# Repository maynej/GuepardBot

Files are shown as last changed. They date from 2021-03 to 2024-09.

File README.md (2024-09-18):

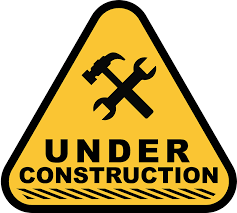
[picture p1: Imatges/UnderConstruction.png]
# GuepardBot 

STEMFIE adaptation to Baby MIT Cheetah 

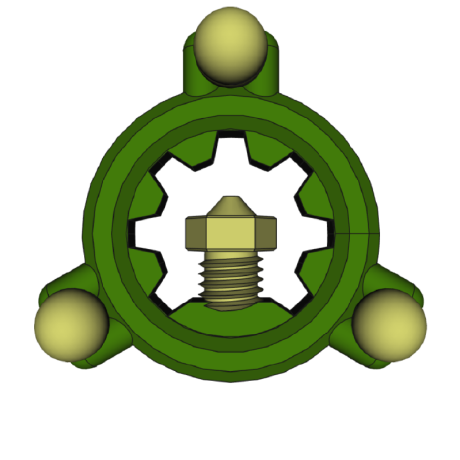
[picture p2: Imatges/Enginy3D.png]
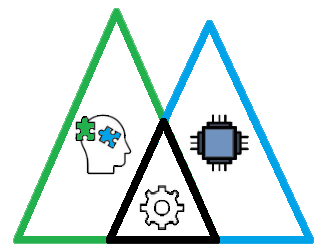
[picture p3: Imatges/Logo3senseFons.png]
Iniciat per [Artur Binefa](https://github.com/enginy3D) de enginy 3D  amb Freecad, i realitzat per [Jordi Mayné](https://github.com/maynej) des de Mechatronic Study 

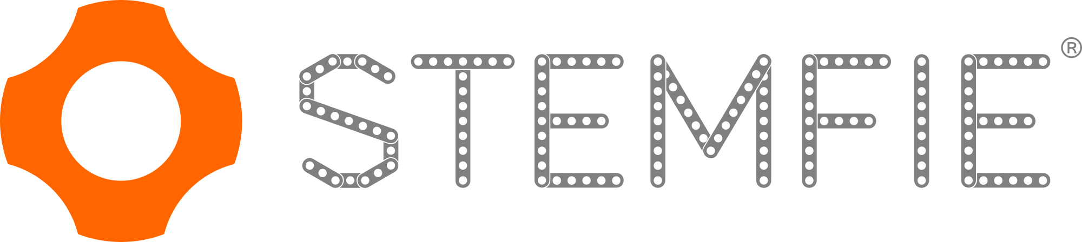
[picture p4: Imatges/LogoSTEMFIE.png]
STEMFIE es un projecte de construcció lliure, que s'imprimeix en 3D (http://stemfie.org) 

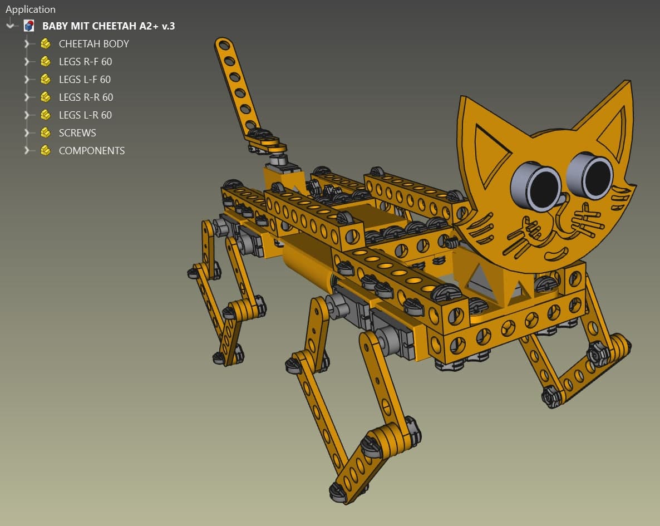
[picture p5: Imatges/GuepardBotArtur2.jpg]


Tota la [documentació es pot trobar en PDF](https://github.com/maynej/GuepardBot/tree/main/DOC).

STL per imprimir GuepardBot [aquí](https://github.com/maynej/GuepardBot/tree/main/STL).

## Suports 3D
  
Descripció         | Imatge          | Arxiu         
------------- | ------------- | ------------- 
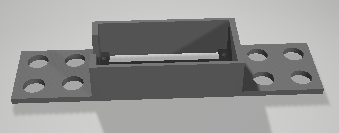
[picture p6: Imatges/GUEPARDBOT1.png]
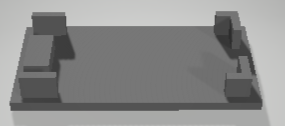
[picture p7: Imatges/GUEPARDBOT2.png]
Suport Arduino Nano i tapa |  | [Arduino Nano](STL/ArduinoNanoStemfie.stl), [Tapa Arduino Nano](STL/TapaArduinoNanoStemfie.stl)
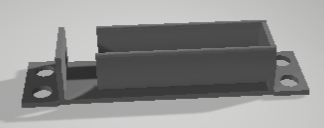
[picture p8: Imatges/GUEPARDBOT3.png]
Suport Bateria Li-ion 18650| | [18650](STL/18650.stl)
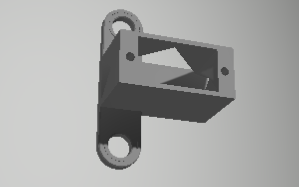
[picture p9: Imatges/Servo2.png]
Suport Servo-motor SG9|  | [ServoSuport 3H](STL/ServoSuport4migStemfie.stl), [ServoSuport 3V](STL/ServoSuport3VStemfie.stl)
Suport palanca Servo-motor SG9| |[Adapter SG9](STL/Servo9GAdapter_Stemfie.stl)
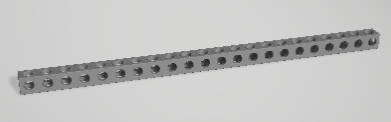
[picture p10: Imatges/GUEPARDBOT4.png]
Biga 22 | | [Biga 22](STL/Beam22.stl)
Biga 6 | | [Biga 6](STL/Beam1x1x6.stl)
Biga 4 | | [Biga 4](STL/Beam1x1x4.stl)
Tensor 4 | | [Tensor 4](STL/BraceSTR_ERR_BU04x01x00.25-SPN-BRC-0003.stl)
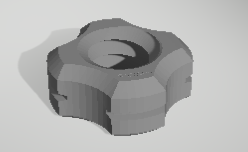
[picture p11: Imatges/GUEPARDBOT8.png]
Femella | | [Femella](STL/NutRH_BU01.00x5mm-SPN-NUT-0001.stl)
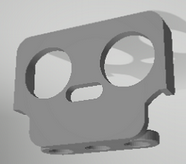
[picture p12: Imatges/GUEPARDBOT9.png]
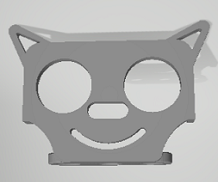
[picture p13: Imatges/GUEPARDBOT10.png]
Cara Guepard |  | [Cara Guepard](STL/SensorAsimetric3H_STEMFIE.stl)
Cargol BU00.50 | | [Cargol BU00.50](STL/ShoulderScrewRHD_RH_BU00.50-SPN-SSC-0042.stl)
Cargol BU00.75 | | [Cargol BU00.75](STL/ShoulderScrewRHD_RH_BU00.75-SPN-SSC-0043.stl)
Cargol BU01.25 | | [Cargol BU01.25](STL/ShoulderScrewRHD_RH_BU01.25-SPN-SSC-0045.stl)
Cargol BU02.00 | | [Cargol BU02.00](STL/ShoulderScrewRHD_RH_BU02.00-SPN-SSC-0048.stl)
Volandera | | [Volandera](STL/NutRHBU01.00x5mm-SPN-NUT-0001.stl)

## QR


## Llicència

Creative Commons Attribution-NoComercial-ShareAlike 4.0 International (CC BY-NC-SA 4.0)

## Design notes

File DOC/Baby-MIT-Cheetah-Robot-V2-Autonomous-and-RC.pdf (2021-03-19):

instructables

Baby MIT Cheetah Robot V2 Autonomous and RC (http://www.instructables.com/id/Baby-MIT-Cheetah-Robot-V2-Autonomous-and-RC/)

by jegatheesan.soundarapandian (http://www.instructables.com/member/jegatheesan.soundarapandian/)

Very Very Sorry Now only found the legs design in the tinkercad has problem, thanks to Mr.kjellgnilsson.kn (https://www.instructables.com/member/kjellgnilsson.kn/) for check and inform me. Now change the design le and upload. Kindly check and download. Those who already download and printed I am very very sorry, i never notice and dont know how it change.

Actually that previous design also works but the joint is very thin and it break while fast steps.

Baby MIT Cheetah Robot (https://www.instructables.com/id/Baby-MIT-Cheetah-Robot/) is the previous version of this robot. I did lot of changes in this version. But even more want to done. But this version very very simple for any one to design. In the previous Version Body is made of wood but in this version i 3D print the body so if any one want to this this robot its very very easy to do. Just download and print the body and leg, then screw the servos.

I plan for the top cover after complete the project, but current due to state wise lock i cant able to get the cover from supplier. Even though it looks cute on carrying two batteries like Robot cow bulk in the

stomach.

This is not upgraded from old its completely new build. So all the steps are included in this instructables, you dont want to refer the version1 instructables.

M ajor changes Done

1) Body is 3D printed.
2) Its Bluetooth control as well as Autonomous.
3) Battery Operated (The strong battery 18650 2Nos allow to run for long hours, From start design to complete i test it for more than 2 hours but still work in battery).
4) Lot of changes in the arduino program, we able to change the moving speed. If we have foot for the robot, it never fall and at that time change the variable smoothdelay in the program and even we see the slow motion walk.

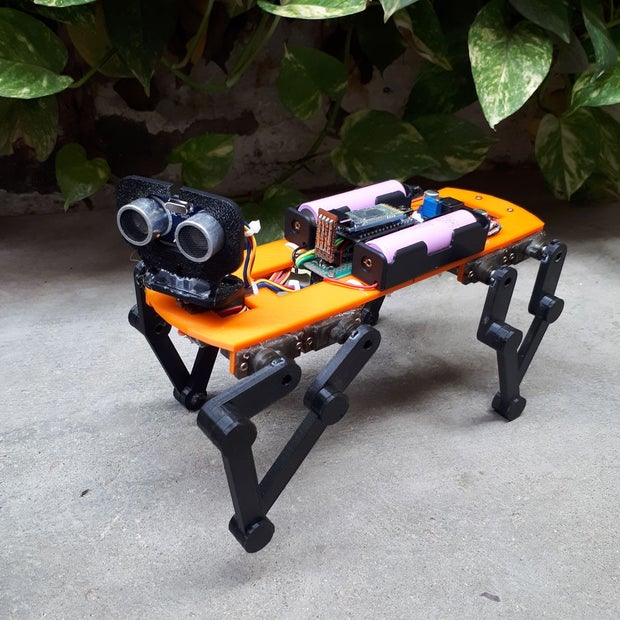
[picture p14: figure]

Baby MIT Cheetah Robot V2 Autonomous and RC: Page 1

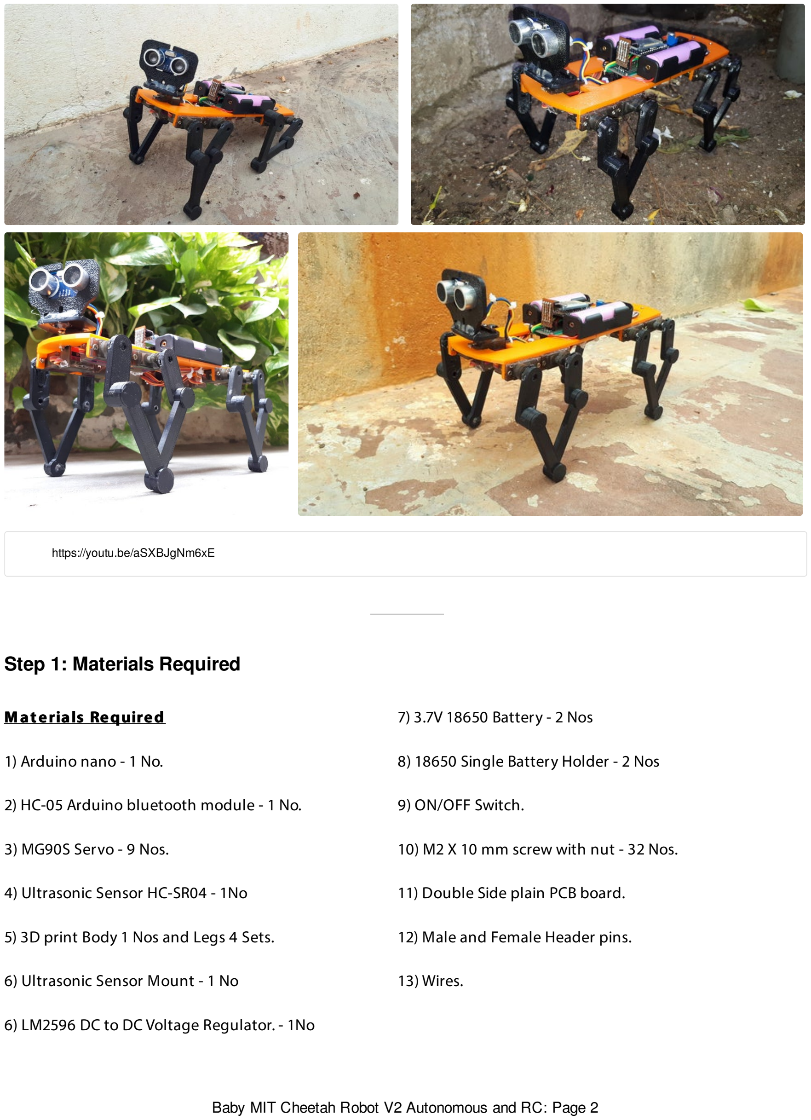
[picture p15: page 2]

### Step 1: Materials Required

https://youtu.be/aSXBJgNm6xE

M at erials Required

1) Arduino nano - 1 No.
2) HC-05 Arduino bluetooth module - 1 No.
3) MG90S Servo - 9 Nos.
4) Ultrasonic Sensor HC-SR04 - 1No
5) 3D print Body 1 Nos and Legs 4 Sets.
6) Ultrasonic Sensor Mount - 1 No
6) LM2596 DC to DC Voltage Regulator. - 1No
7) 3.7V 18650 Battery - 2 Nos
8) 18650 Single Battery Holder - 2 Nos
9) ON/OFF Switch.
10) M2 X 10 mm screw with nut - 32 Nos.
11) Double Side plain PCB board.
12) Male and Female Header pins.
13) Wires.

### Step 2: 3D Print Leg

### Step 3: 3D Print Body

### Step 4: Circuit Plan and Develop

Use Tinkercad (http://tinkercad.com/) to design the Legs and Body. And 3D print it in A3DXYZ. (https://a3dxyz.com/) https://www.tinkercad.com/embed/jtZIKGD5QBL?editbtn=1

Download the Tinkercad Files and Print it. Some holes are put in the body while xing and wiring.

https://www.tinkercad.com/embed/a8EDaNkRZpk?editbtn=1

As per plan we want to drive 9 servos. So i user Digital pins 2 to 10. Connect the pin to the servo pins using male connector. Arduino TX RX is connected to bluetooth RX and TX, Ultrasonic sensor Echo and Trigger connected to Pins A2 and A3 and power supply for bluetooth and Ultrasonic sensor is given from arduino 5V. For Arduino Vin is given directly from 2 3.7V battery 18650. For servos Supply given from same 18650 but through LM2596 voltage regulator.

I use double side PCB to make shield. While use double side PCB be careful while creating track in the

PCB, Molten lead pass through the holes and ll in the next side. Use Female header pins in the double side PCB to connect the arduino nano and in the opposite side of the board use male header pins to connect the servos, I soldered 12 male connectors from 2 to 13. Solder female header pins to connect the HC-05 bluetooth module on the board. And Male header pins for Ultrasonic sensor. Four male header pins from GND, Vin of the arduino, dummy and last one for servos vin. The Circuit is very small.

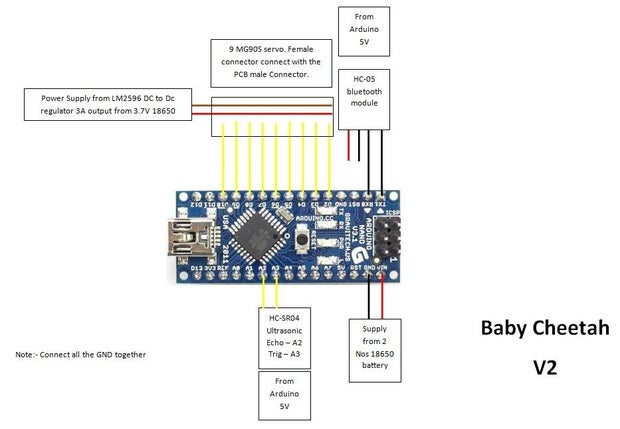
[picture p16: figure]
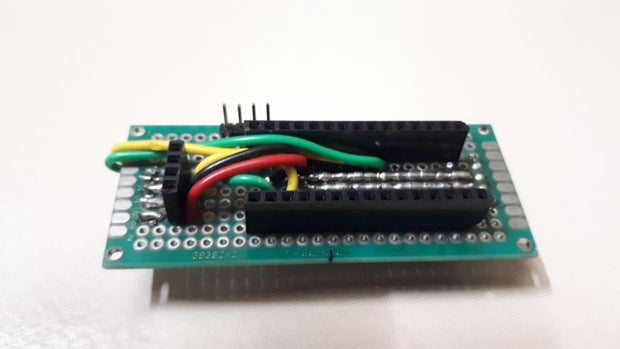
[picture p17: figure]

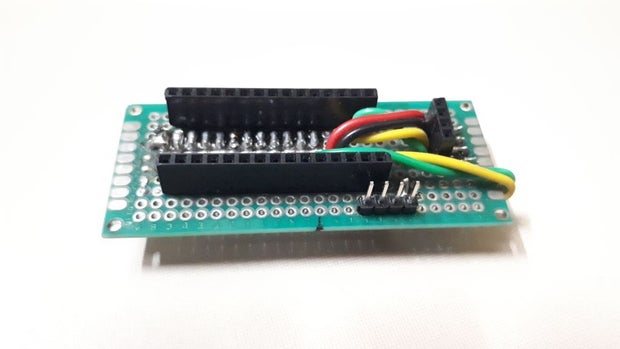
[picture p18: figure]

### Step 5: Assemble Leg

There are 7 pieces in the a single set leg. Like wise 4 sets available. Join the leg links where two pieces connected with servo has a servo horn slot on the back side and its is 30mm length hole to hole. and the link pieces are 6 cm from hole to hole.In the 3D model i set only 0.1mm diHerence gap for links, so it hold very tight. I use ne emery sheet to increase the hole size and x the links.First join the left side and then the right side and then the bottom.Now use the top screw like cap to hold the links. Join all the four sets.

The screw like plastic piece extend up to the back side of the links. Use feviquick (quick xing liquid) to paste the holder permanently with the legs. Be careful while pasting, Don't allow the feviquick to Low inside the moving joins. Then fully paste the servo horn on both side of the leg. Now check and found the movement is correct. The links are 5mm thick so its hard.

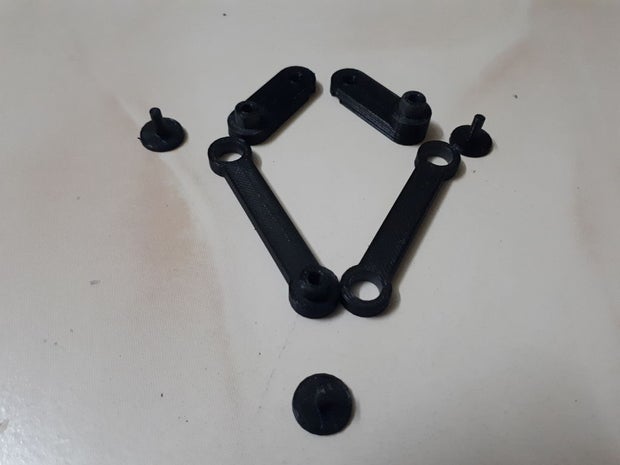
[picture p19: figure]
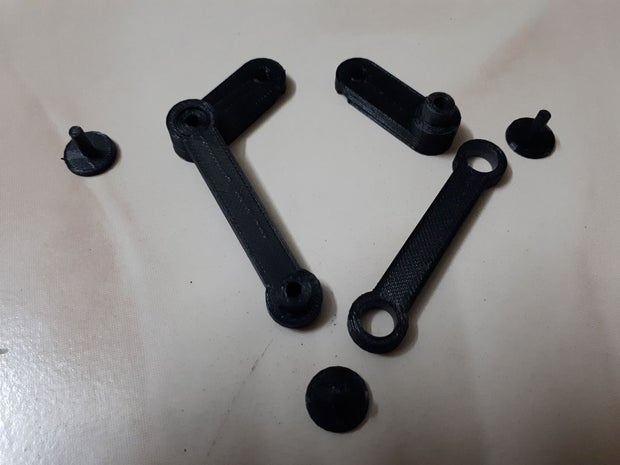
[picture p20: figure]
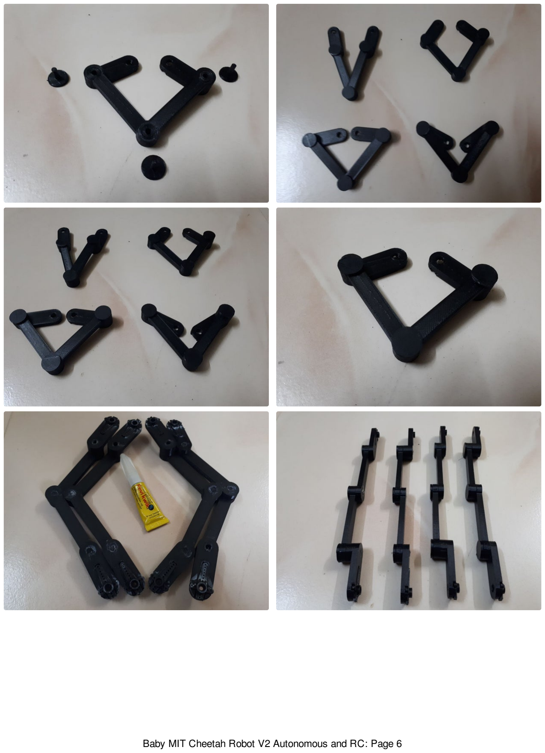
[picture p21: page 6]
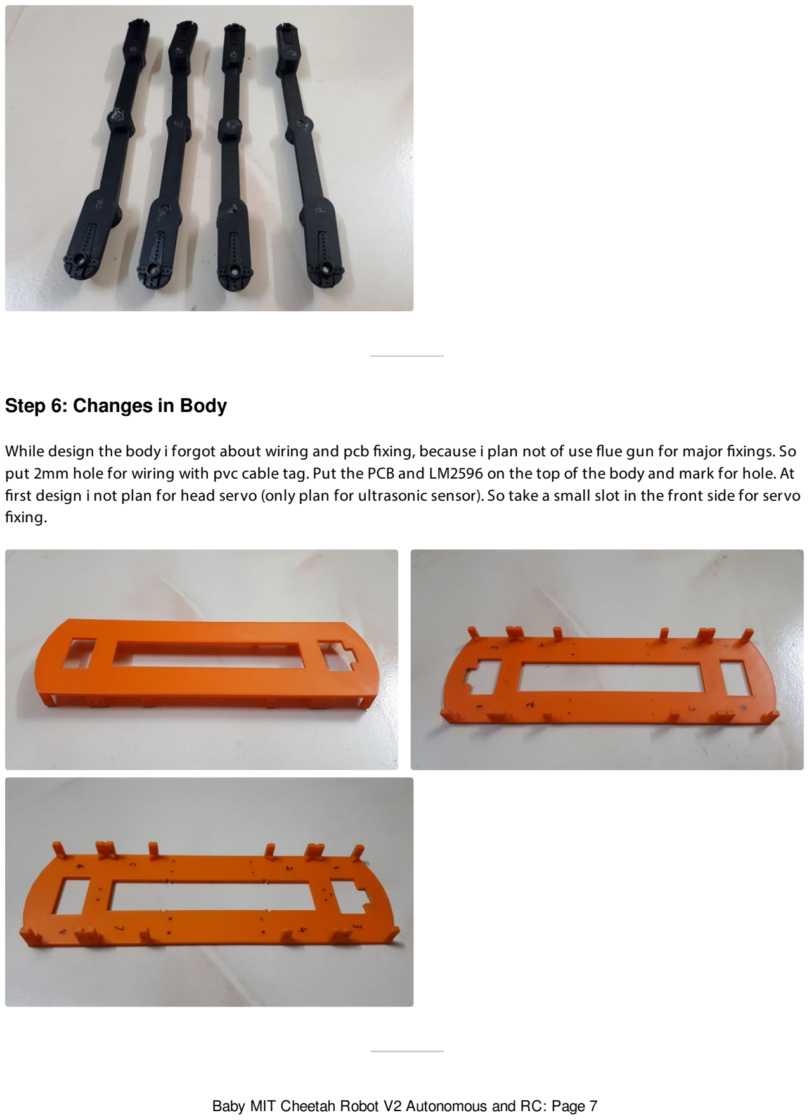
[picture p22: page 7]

### Step 6: Changes in Body

While design the body i forgot about wiring and pcb xing, because i plan not of use Lue gun for major xings. So put 2mm hole for wiring with pvc cable tag. Put the PCB and LM2596 on the top of the body and mark for hole. At rst design i not plan for head servo (only plan for ultrasonic sensor). So take a small slot in the front side for servo xing.

### Step 7: Screw Servos With Plan

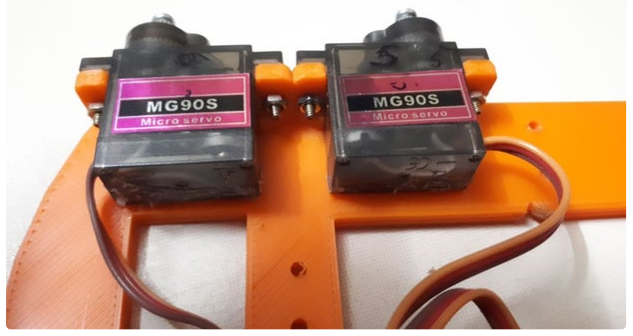
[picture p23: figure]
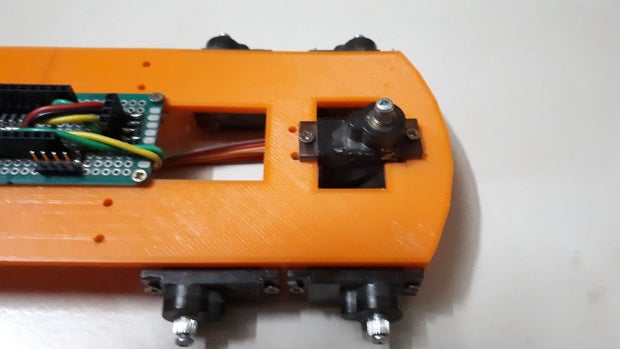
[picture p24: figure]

### Step 8: Screw Circuits

First step is to x the servos. This project has 9 servos. Servos pin connection pin no, name in arduino program and location marked in the rst image. I use M2 X 10mm screw and nut (At rst plan for nickel screw but while see the force of the leg while walking i feel if screw and nut is use then its very tight and not damage while walking). Screw all the servos as like the photo and as per the pin number hot glue the servo connectors one after the another. So its very easy to plugin and also no chance to change the pins.

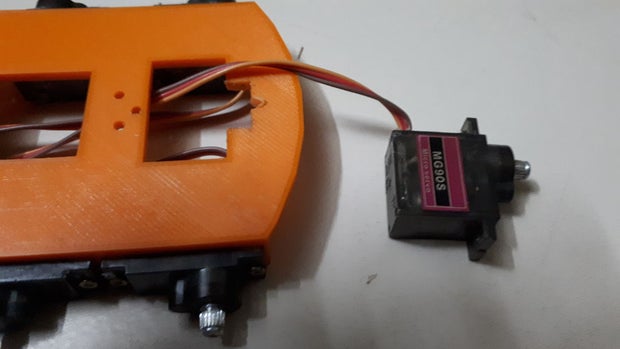
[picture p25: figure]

Put the shield over the body and screw it in the edges with the body on all four sides in the slot. Mark a center line in the body and keep the circuit center with the body center. Screw the DC to DC regulator board LM2596 on the back side of the body.

### Step 9: Power Supply Wiring and Checking

ON/OFF Power switch which i got is the screw option on the front. So i cut a small plain pcb and tie the switch in that pcb and hot glue it. Now put 2mm hole on both side in the pcb. Mark that holee in the back of the body and drill it. Screw the switch with 2mm bolt and Nut. Soldering the battery positive wire through this switch to the LM2596 dc to dc regulator input.

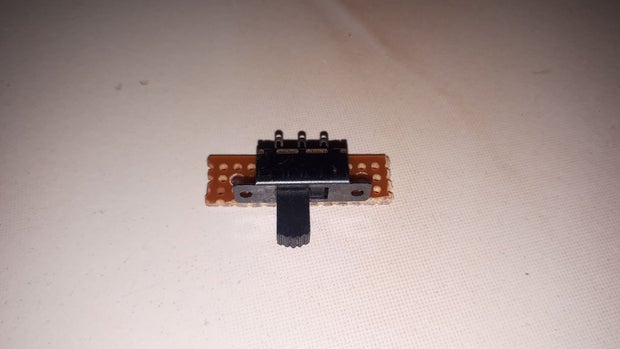
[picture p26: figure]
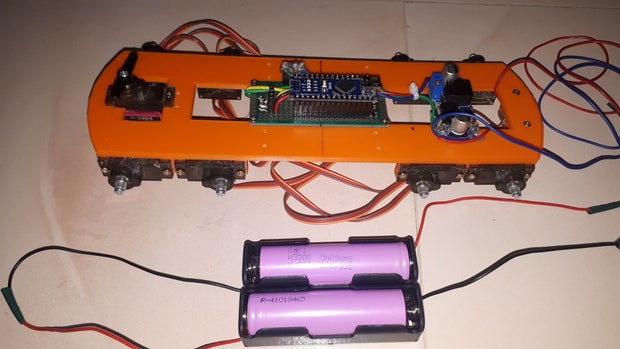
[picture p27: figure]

### Step 10: Under Devepment Work Place

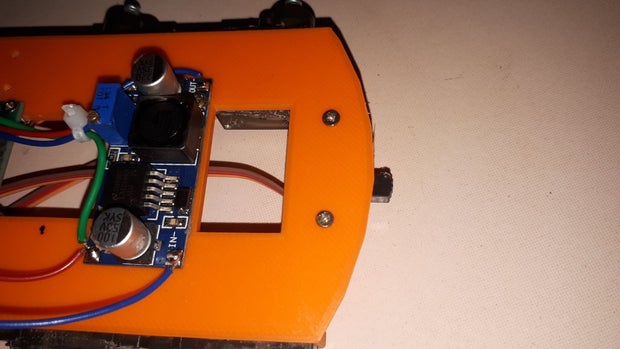
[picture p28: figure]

### Step 11: Head Fixing (Ultrasonic Sensor Fixing)

My Work place (also my bed room) at the time of developing baby cheetah robot. See the baby cheetah in the center its growing. Can you trace the tools around me. Organize it after work at night 3 is the diMcult task.

Ultrasonic holder is available online. But the horn screw holder is for the SG90 servo screw. So i increase the hole size of the holder and screw the servo horn with the ultrasonic sensor holder. Make a 4 wire female to female header pin wire extension. Already solder male header in the shield with wiring for ultrasonic. Put the head servo to

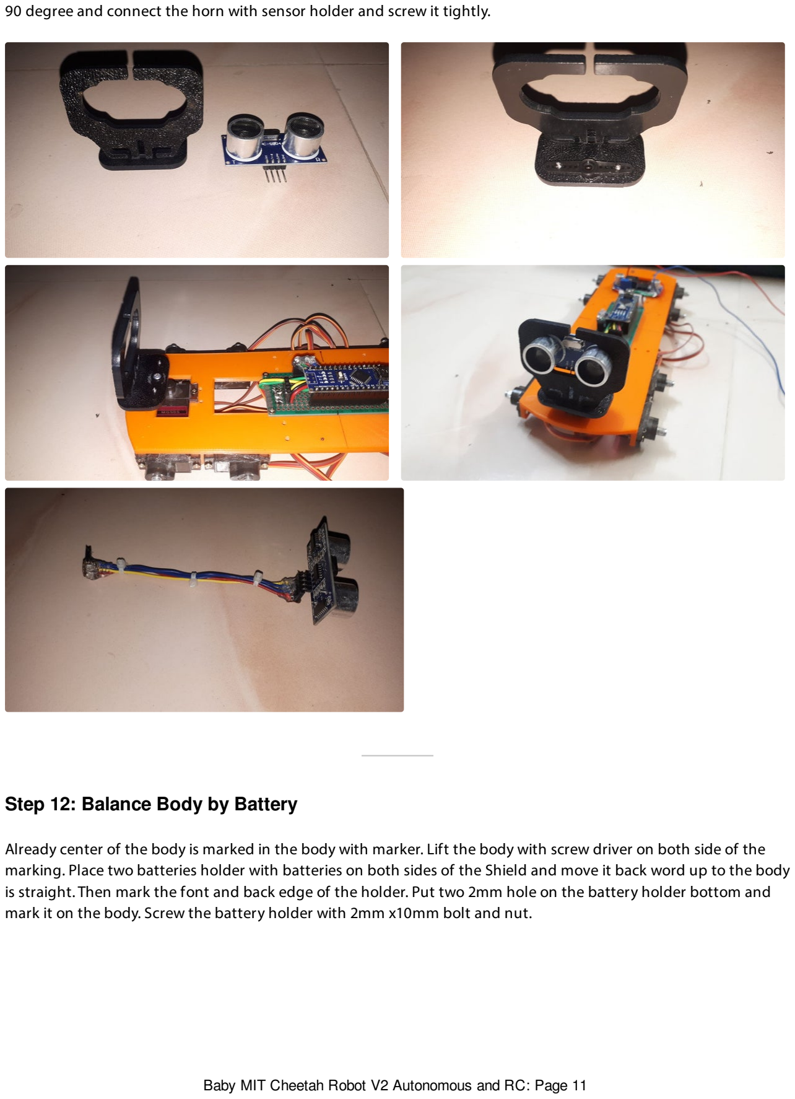
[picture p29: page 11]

### Step 12: Balance Body by Battery

90 degree and connect the horn with sensor holder and screw it tightly.

Already center of the body is marked in the body with marker. Lift the body with screw driver on both side of the marking. Place two batteries holder with batteries on both sides of the Shield and move it back word up to the body is straight. Then mark the font and back edge of the holder. Put two 2mm hole on the battery holder bottom and mark it on the body. Screw the battery holder with 2mm x10mm bolt and nut.

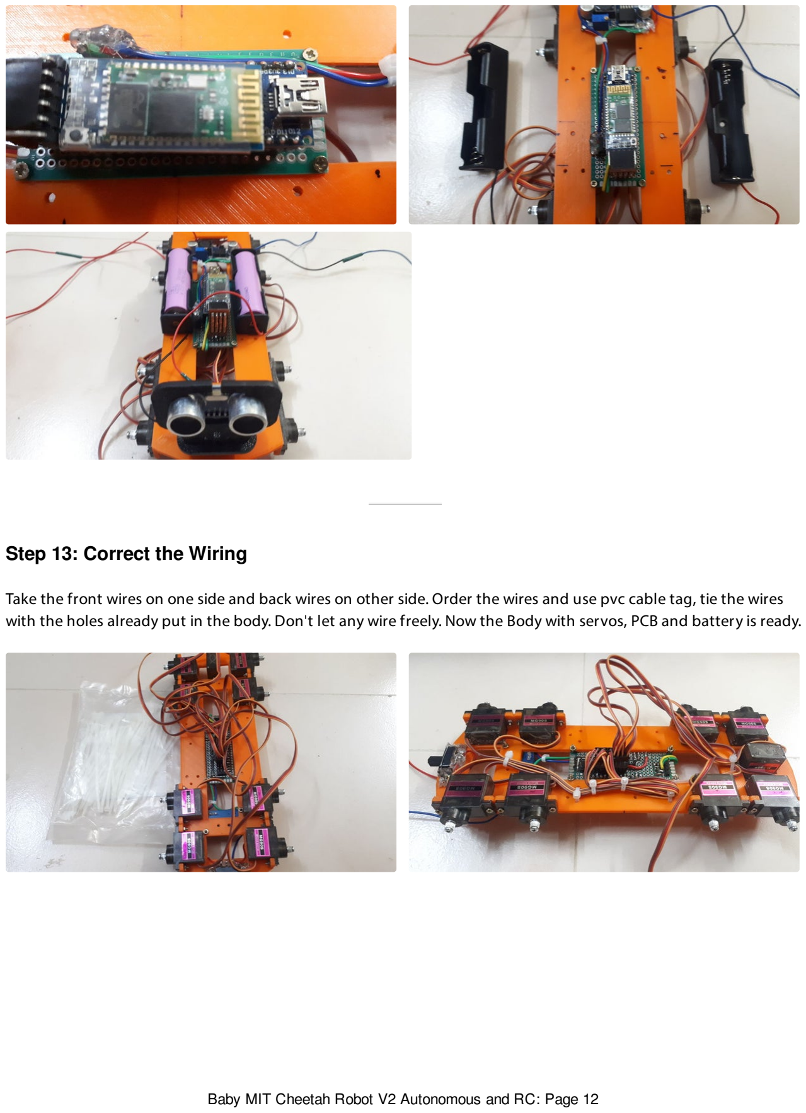
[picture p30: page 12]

### Step 13: Correct the Wiring

Take the front wires on one side and back wires on other side. Order the wires and use pvc cable tag, tie the wires with the holes already put in the body. Don't let any wire freely. Now the Body with servos, PCB and battery is ready.

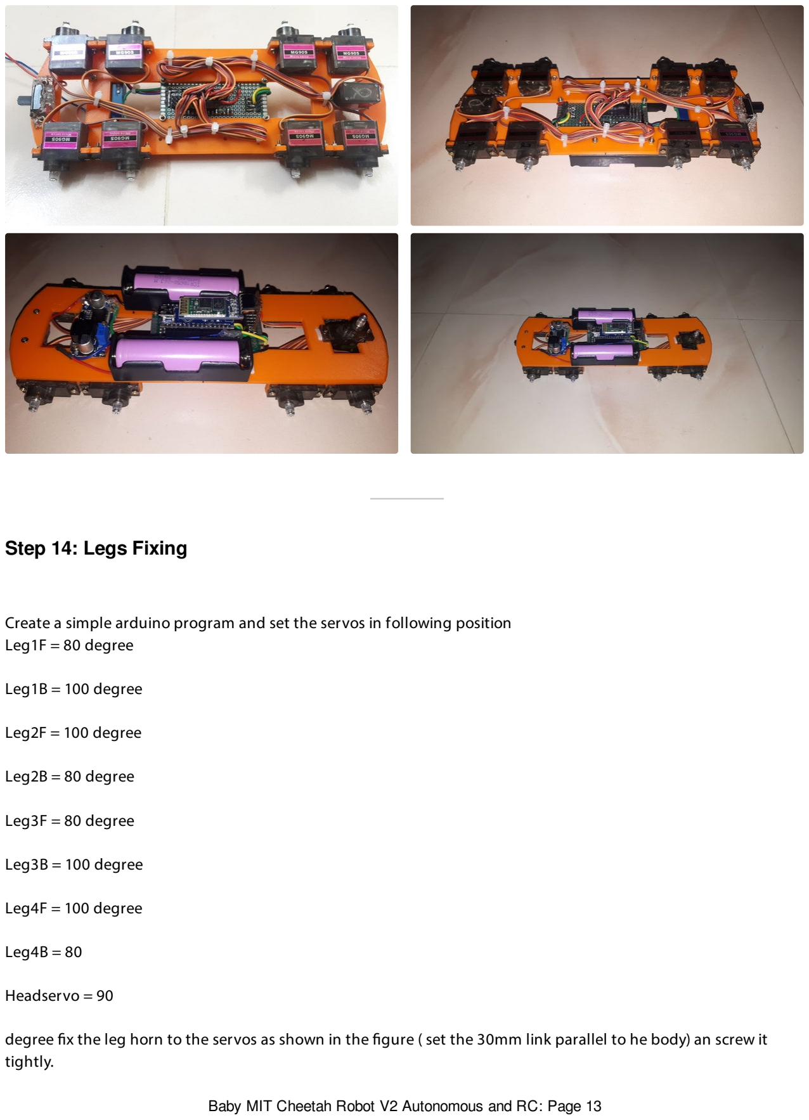
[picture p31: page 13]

### Step 14: Legs Fixing

Create a simple arduino program and set the servos in following position Leg1F = 80 degree

Leg1B = 100 degree

Leg2F = 100 degree

Leg2B = 80 degree

Leg3F = 80 degree

Leg3B = 100 degree

Leg4F = 100 degree

Leg4B = 80

Headservo = 90

degree x the leg horn to the servos as shown in the gure ( set the 30mm link parallel to he body) an screw it tightly.

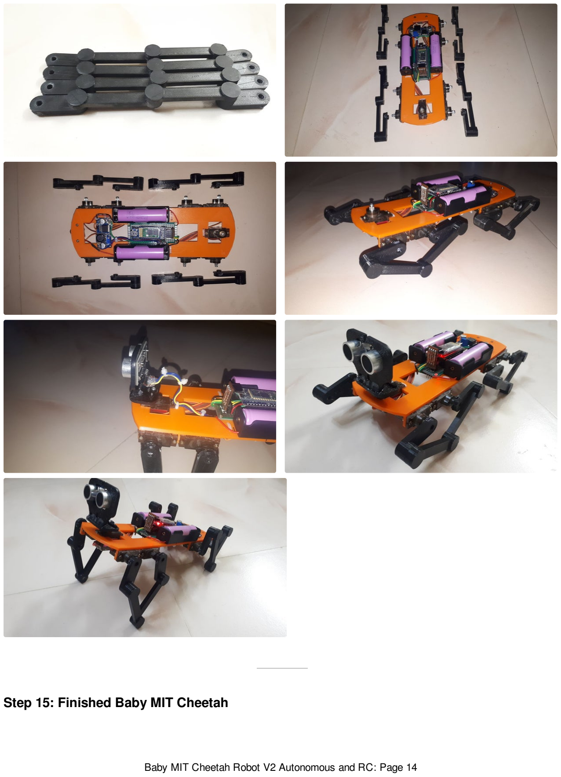
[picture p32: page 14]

### Step 15: Finished Baby MIT Cheetah

### Step 16: Android Code

Download the apk le from here (https://drive.google.com/file/d/1ljjOWiZYqTx6P_n0Vq42K3Er0TnjODdW/view?usp=sharing)

Download the aia le from here (https://drive.google.com/file/d/1TBjouGvm-IVyqHDKxgXw9jgRAbJs5Jhc/view?usp=sharing)

Its a very simple program developed in Android with MIT App Inventor (https://appinventor.mit.edu/) . All the buttons send a character as per press and release image. So far 21 characters used for each action. When arduino received this character through bluetooth it works as per the character received.

Download the app from google drive by click the above link and install it in the mobile.

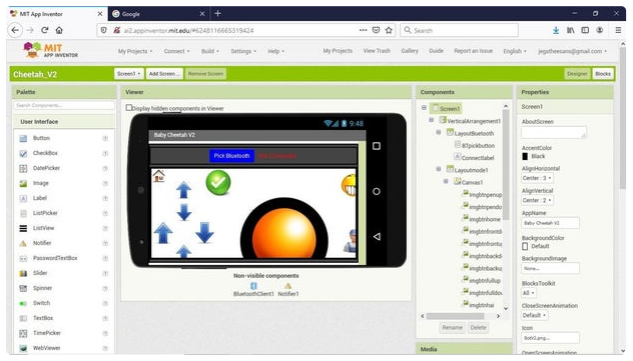
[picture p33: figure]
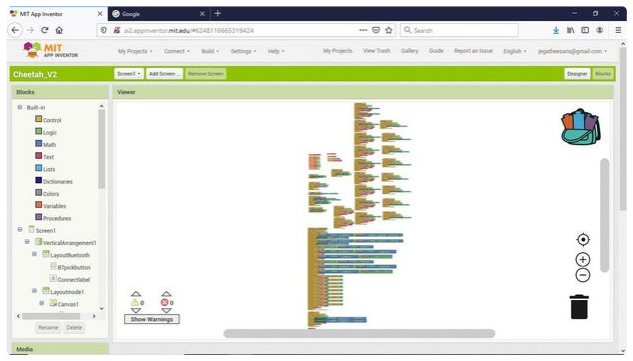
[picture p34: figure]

### Step 17: Keys From Android

List of characters send by the Arduino is given below

G Front left
F Front
I Front Right
L Left
S Stop
R Right
H BAck left
B BAck
J BAck right

U Up
D Down

W Front only down
X Back only down
Y Front only UP
Z Back only UP

O Fullstand
P Fullshit

C Check
V Hai

M Manual
A Auto

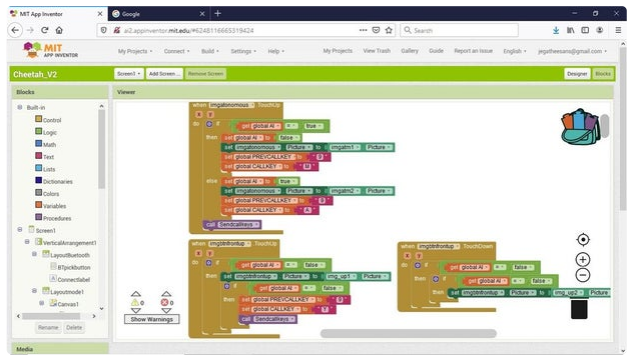
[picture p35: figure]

### Step 18: Run Android App

In the mobile Switch on the Bluetooth and Open Baby Cheetah V2. Click the pick bluetooth and select the arduino bluetooth HC-05. The control screen opens. New addition in the control screen compare to version one is. Auto and manual, if switch to auto then all other buttons are not able to use. Switch to manual mode to activate control.

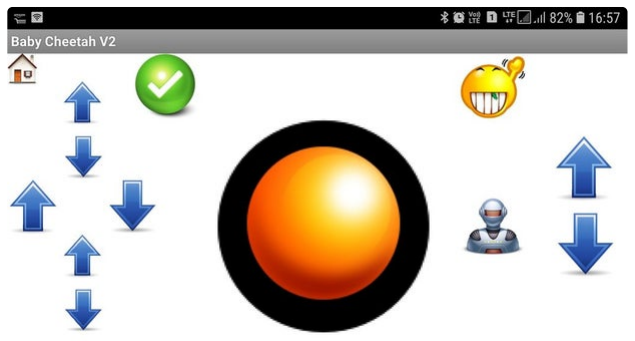
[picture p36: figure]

### Step 19: Arduino Code

### Step 20: Arduino Major Changes

Download the arduino code from Google Drive (https://drive.google.com/file/d/1eyzs1xH_40GEmCUdIiTCoEEMSyVstiyJ/view?usp=sharing)

The main aim of the arduino program is to keep the body in the same position even walk and turn. For

that angle of the leg movement is calculated in each height and put it in a multidimensional array. As per the commands received from the android the program check the array and move the leg in that direction. So the body is in the same height while walk and turn.
Cheetah walk funny like front leg in full height and back leg full down. Like wise wise verse. Like wise it also run in all heights.

M oving speed

In the previous version no servo control is provided so the servo move at its full speed. But in this version a seperate procedure us written for servos speed control. So whole program is changed by intialize the servo position want to move to the procedure. All the 8 leg servo motor last postion is recorded and with the new position nd the max diHerence of all the 8 motors. With that max diHerence divide all the steps want to move individually and with a for loop repeated for max steps with delay, we change the leg speed here.

Autonomous

When you switch the auto mode in the android. Auto run set to true in arduino. In the Autonomous mode the robot move automatically with the help of ultrasonic sensor.

How It works

1) First the robot go to full stand position.
2) Move forward and check the distance of obstacles from the robot.
3) If the distance is more than 5cm then its walk front else it stop.
4) First it reduce the height to up to 4 steps one by one.
5) If the obstacle is just a gate it never found obstacle at reduced height, then it move forward by crealing. After some xed movement it stand up and repeat the action.
6) Even down to 1 height and found the obstacle, it again stand at lle height (5th position)
7) Turn the head degree from 90 to 0 and note the distance and turn head to 180 degree and note the distance. Then head go to 90 degree.
8) Refer the left side distance and right side distance,

turn to the direction with long distance.

9) After turn move to front and goto step 2.

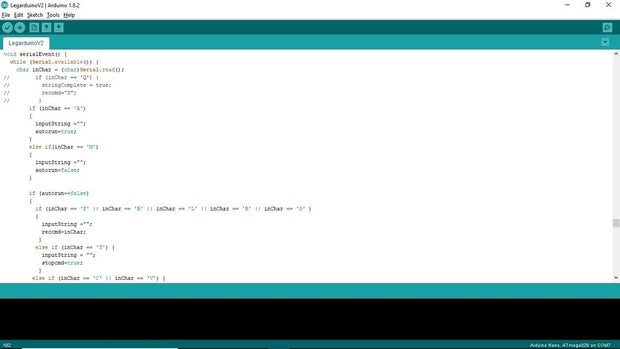
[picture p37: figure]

### Step 21: Autonomous Video

### Step 22: Baby Cheetah in RC Action

Open the App and connect the robot and click to auto mode (man in the app change to robot). Now see the movement, move forward and see a obstacle and reduce its height step by step, even it has obstacle. So it stand up and see left and right, in the left side i put a corrugated board. So right side has long way and it turn right and walk.

https://youtu.be/TQZb3RycQOs

Even through Autonomous mode is very nice. Kids like to play with control. Here are some videos with fun action of the robot. It say hai by show leg and shack heads. Orange black combination is like by all. I plan for the top cover only after x the head and design, but due to lock down i cant able to get the top cover. When cover work completed i put a photo shoot and

upload here.

Thank you for going through my project.

Lot more to enjoy | Don't forgot to
comment and encourage me friends .

Thank you for this great project. Would it be possible to have the .aia file for MIT app inventor please ? Best regards.

Now, I uploaded in google and give the link in step 16 please download it.
thank you so much.
Any chance you have Apple iOS code for this project? I'm making this with my son and we don't have an android device. Are there any other ways of controlling this robot? Our first RC project. The Amazon bill for the parts comes to over $100 CAD, so want to make sure it's money well spent to introduce my son to robotics. I really like the looks and description of this project.
Sorry sir i have no apple phone and i dont know how to code in ios. But MIT app inventor has new options to code in ios, may you try it..... Its very easy to program in MIT app inventor even i have no basic knowledge in android but i able to create app in android.
Sounds like something worth learning. You make it sound easy enough for my kids to learn and use too. :)
I have been
looking at your code, and would like to make several constructive
criticisms. 1. There are virtually no
comments in the code, which makes it difficult to follow. 2. There are many
lines which have been commented-out. Are this needed or can they be deleted? 3. There is a section (lines 142 – 150) that appear to be the initial servo setup positions, prior to attaching them. Is this correct? 4. There is no indication
which leg is which. Is leg 1 the Front Right and Leg 2 the Rear Right? 5. You have not included your name in the code. With such a great project, you should give yourself credit and include your name as the author. Please take these as constructive.

I have
designed and printed a TPU ‘foot’ and will let you know how it works.

Regards. Tony

1) Sorry i develop step by step so i don't comment.
2) Comment lines are not require u better delete it.
3) Yeah it is the initial servo setup but even it comment same is done in Servomovement(), so no need to uncomment for set up use the same program once setup run its is in the inital stage.
4) see step 7 ist image the image detailed the servo position.
5) Thank you for your complements. For more details feel free to mail me.
Hi, Really Nice project !!!
I`m thInking about build one myself. But instead of using those 18650 Batterys, I would use one of those cheap chinese Powerbanks(No need for the LM2596 voltage regulator). With an ESP32 dev kit that already has onboard Bluetooth. Would make it lot easyer.

Thank you very sir....
ESP32 is a nice idea. But using power bank is not good idea because at first i try in some other project and found while servo working it draw more current and sudden variation in voltage, this make the arduino 5v supply to reduce power and Arduino restart at when ever servo start, because the power bank out put is only 5v its is the minimum voltage for arduino. Also most of the power banks has 18650 batteries inside with same dc to dc power regulator. If you have power bank try it and send the result.
Very Very Sorry Now only found the legs design in the tinkercad has problem, thanks to Mr.kjellgnilsson.kn (https://www.instructables.com/member/kjellgnilsson.kn/) for check and inform me. Now change the design file and upload. Kindly check and download. Those who already download and printed I am very very sorry, i never notice and dont know how it change.

Actually that design also works but the joint is very thin and it break while fast steps.
Links Final Print on TinkerCAD shows edited 2019. Is this the latest or am I looking in the wrong place? Thanks!
Yeah it is the last one i start make this project in 2019 with my first version.
Caught my attention... I'm a small robot fanatic and this one really simple and cute to have! Thank you very much
Very nice project. Your Bill of Materials says 8 sets of legs but don't we only need 4?
Thank you very much.......Sorry i wrongly entered, now i changed the sets thank you very much... It's really good but:
It needs rubber feet so it can get a foothold. It's like walking on ice as it is,
Tjhank you very much.....yeah rubber in feet is better but for turning we want slippery floor. Please check my previous version the leg movement is calculated as per walk so with out rubber also not affect walk. But want to extend the leg that reduce the tilt while two leg in air.
Counl an Arduino UNO be used instead of a nano?
Yeah sure...
you don;t seem sure - is it because the nano is smaller/newer or you don't agree with the UNO for some functional reason?
For this project U can use UNO also, because i dont use any advance library i use only digital pins to control servo. But for this frame uno is over size. U want to put the board over the battery...
The sequel we probably didn't deserve, but we needed all the same!

Thanks for giving this little bot a remake - an idea this good definitely deserved it.
Thank you very much...
Very nice and innovative project. I like the leg action. I suggest adding another servo for a tail. Also, an audio output so your cat could purr or growl, or a dog version could bark.
Thank you very much...I plan to add another 4 more servos for walk side wise like MIT Cheetah.... Awesome project and very well written instructable! Even the previous version deserved being featured. Congratulations, man
Thank You very much...
This will be my next project, good work. I will try to add a TPU foot to the base of the leg. Also, I will use an HM10 Bluetooth module to connect to my iOS device. Do you know if there is a similar app builder for iOS? Thanks

Try it its very interesting. I have no idea about ios. But MIT App inventor now launch new page for ios developer.

Thank you very much....Try it its very easy.....I have some other plan to make it more easy if you able do it. In the leg make the joints easy remove then no need to stick.

Awesome build,! Will be printing this shortly lol
It is a gteat little concept and will follow your progress on it. An idea is to add a 16ch servo controller that would free up a lot of pins for other sensors/audio etc. :)
Thank you very much.....Yeah in previous version also some persons suggest it....due to i want to bring all in one shield i never try that. If more sensors in the future i force to use it.
That's doggo not cheetah. Cute build though! Keep it up.

Thank You very much
so good, keep it up buddy
Thank You very much.....
did you have ultrasonic sensor in the V1? the one with the blue cover on the body. I am doing a project but I cant seem to find any plastic that the ultrasonic sensor can see thru, any ideas? thanks in advance.
V1 is a basic version it has no ultrasonic sensor and no batteries. Even lot of arduino code is updated in V2.
Awesome. I would like to try. kindly can you send me the dimensions for the body and legs. Thank you very much....step2 and step3 you can able to download the tinker card file. If you want to print use it or open it in tinkercard and you able to find the dimension. It you want to do it manually please refer my previous version https://www.instructables.com/id/Baby-MIT-Cheetah-Robot/. (https://www.instructables.com/id/Baby-MIT-Cheetah-Robot/)
Buen proyecto trataré de recrearlo saludos desde la mitad del mundo Ecuador.
Muchas gracias señor ...

Thank you very much sir.... Its very easy to make it give a try....One small suggestion while design for leg foot join increase the height of the cylinder by 1 inch in the cap and in the base piece. So the robot not tilt even walk in very slow motion. For walk in slow motion increase the smooth delay in the program.
awesome project
Thank You very much sir........
nice clean build and well written instructable! thanks for sharing! Thank You very much sir....

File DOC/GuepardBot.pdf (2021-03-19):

JORDI MAYNE V0 – 2021 | 1

## GuepardBot

GuepardBot es una rèplica del Baby Cheetah https://www.instructables.com/Baby‐MIT‐Cheetah‐Robot‐V2‐Autonomous‐and‐RC/ feta amb estructura Stemfie.

El Skecth de funcionament és el mateix de Baby Cheetah, també l’aplicació per el smartphone/tablet.

Material Electrónic

1x Arduino Nano

2x Bateries 18650 3.7V amb terminals

9x servos SG9

1x Sensor de ultrasons HC‐SC04

1x Bluetooth HC‐05

1x Placa regulador LM2596

1x Interruptor

Material 3D

2x Beam 22

2x Beam 4

1x Beam 6

8x Servo Suport 3V Stemfie

1x Servo Suport 4mig Stemfie

34x Nut BU01.00x5 ‐SPN‐NOT‐BU0001

30x BU01.25 ‐ SPN‐SSC‐0045

2x BU02.00 ‐ SPN‐SSC‐0048


2x 18650


1x CPU Arduino Nano


1x Tapa Arduino Nano

1x Suport SensorAsimetric 3H

1x Servo9G Adapter

1x Brace BU04x01x00.25 ‐ SPN‐BRC‐0003

1x Screw BU00.75 ‐ SPN‐SSC‐0043

1x Screw BU00.50 ‐ SPN‐SSC‐0042

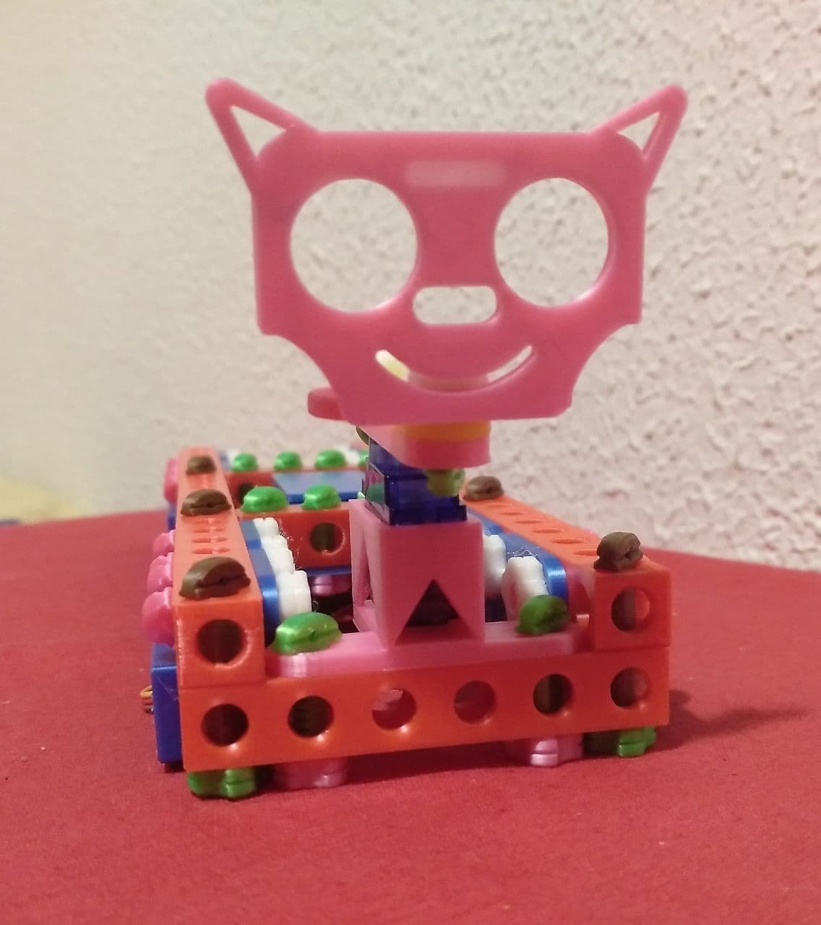
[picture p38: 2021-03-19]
Imatges/Guepard1.jpg

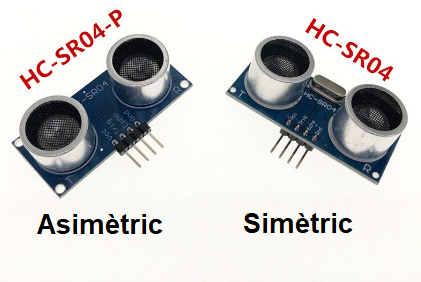
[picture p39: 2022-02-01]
Imatges/HC-SR04P vs.png

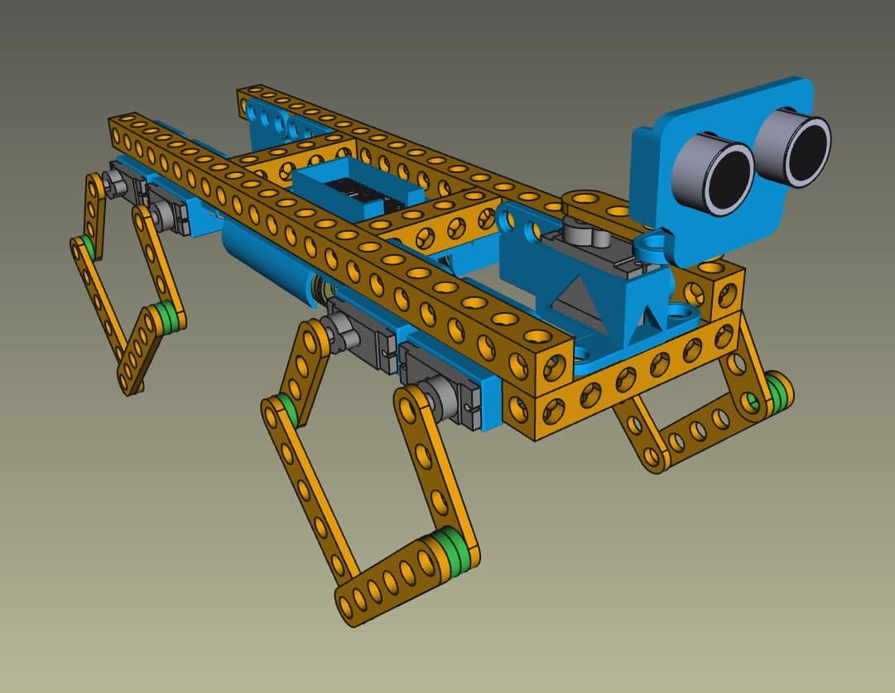
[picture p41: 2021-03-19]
Imatges/GuepardBotArtur1.jpg

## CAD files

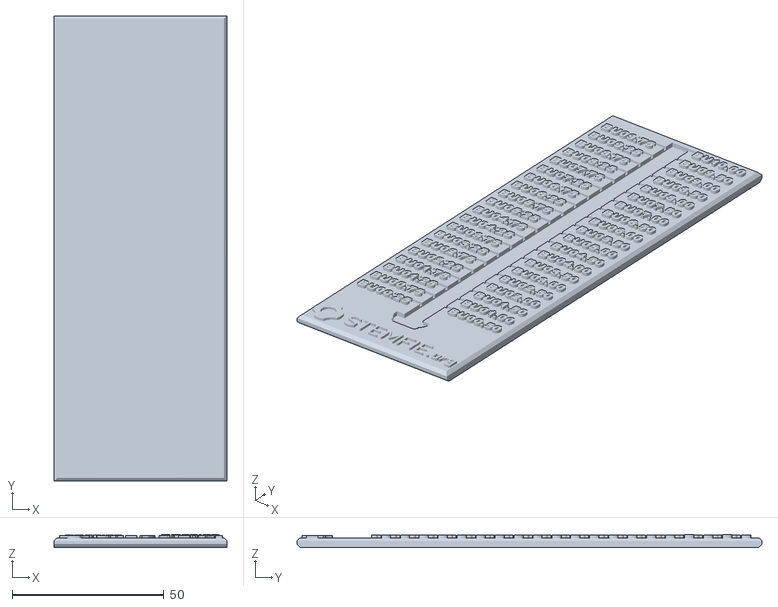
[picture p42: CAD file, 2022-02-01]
STL/MesuraStemfie2.stl
57.0 x 153.4 x 4.13

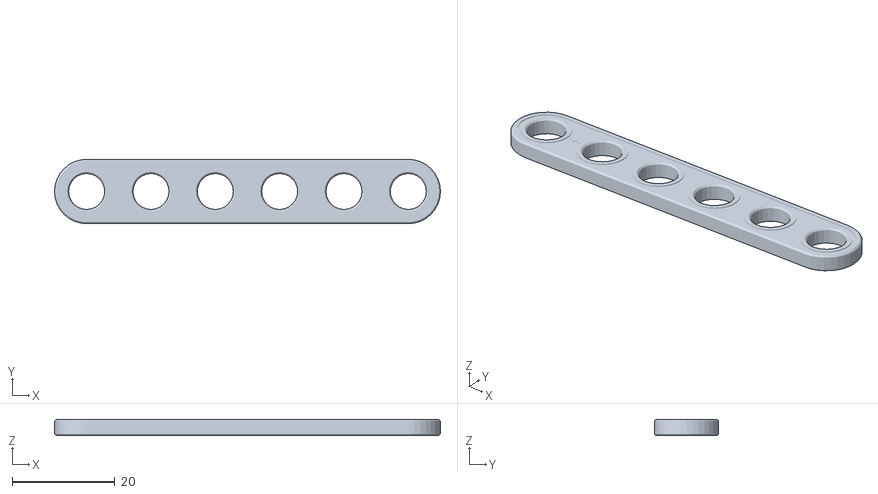
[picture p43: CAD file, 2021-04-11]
STL/BraceSTRERRBU06x01x00.25-SPN-BRC-0005.stl
75.0 x 12.5 x 3.12

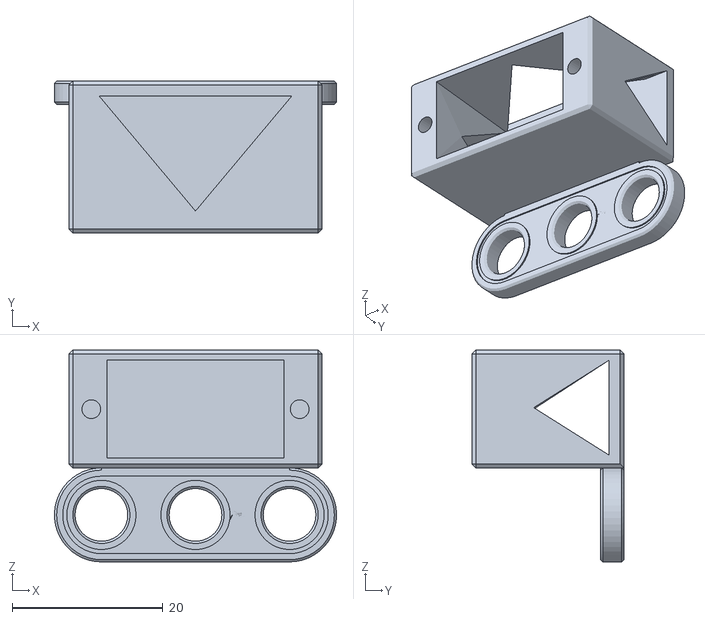
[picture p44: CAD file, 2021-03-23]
STL/ServoSuport3VStemfie.stl
37.5 x 20.2 x 28.2

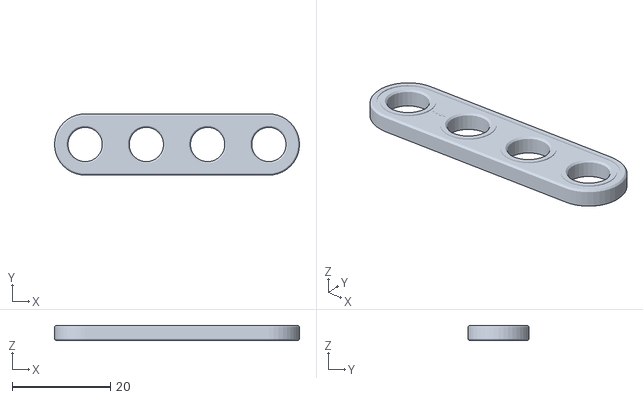
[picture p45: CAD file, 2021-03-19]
STL/BraceSTR_ERR_BU04x01x00.25-SPN-BRC-0003.stl
50.0 x 12.5 x 3.12

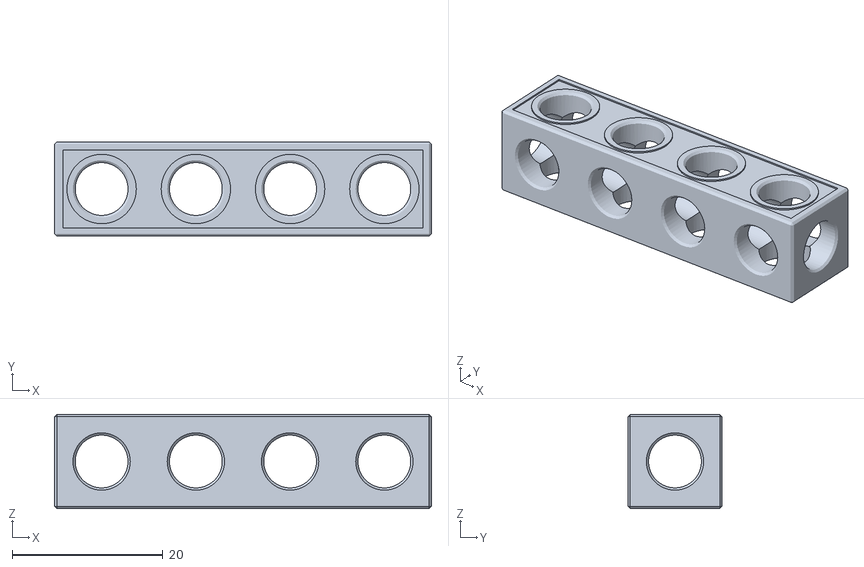
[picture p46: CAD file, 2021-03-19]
STL/beam1x1x4.stl
50.0 x 12.5 x 12.5

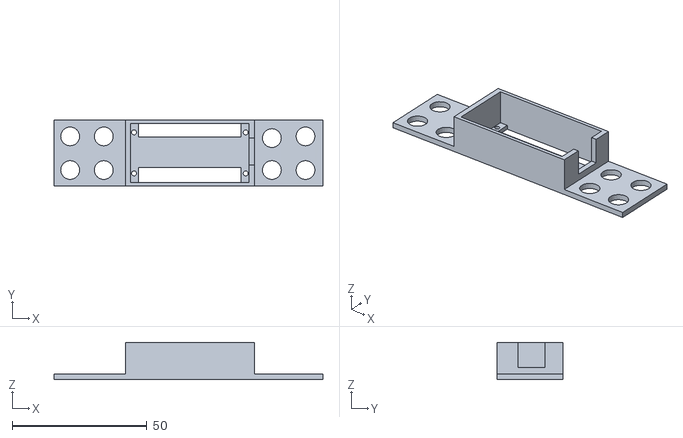
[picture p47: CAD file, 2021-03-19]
STL/ArduinoNanoStemfie.stl
100.0 x 24.7 x 13.8

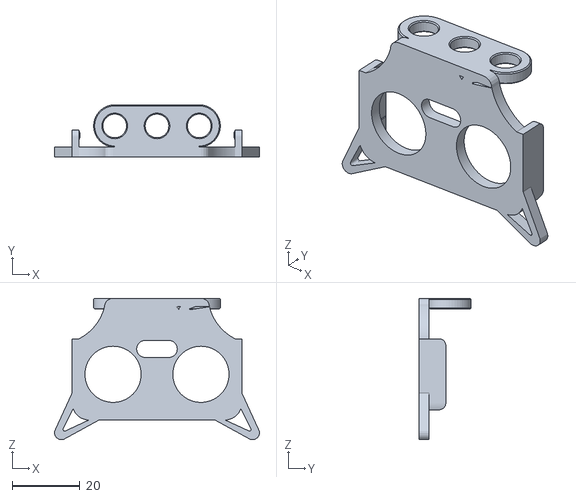
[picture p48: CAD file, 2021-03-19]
STL/SensorSimetric3HGuepardBot_STEMFIE.stl
60.6 x 15.5 x 41.8

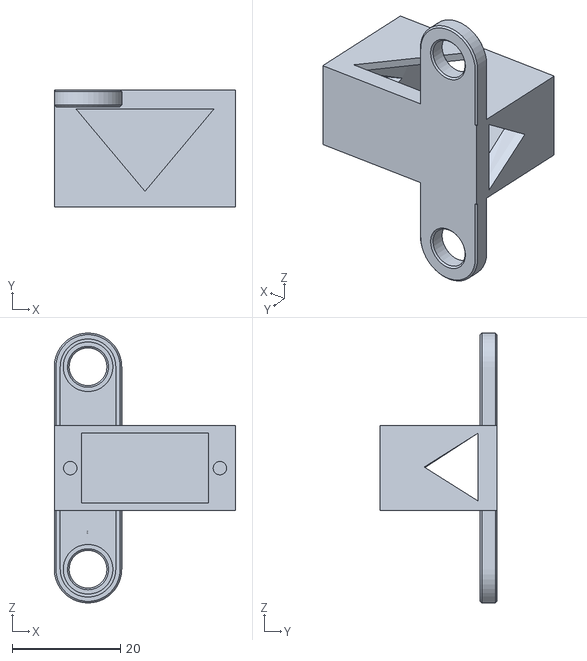
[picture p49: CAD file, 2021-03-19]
STL/ServoSuport4migStemfie.stl
33.6 x 21.7 x 50.0

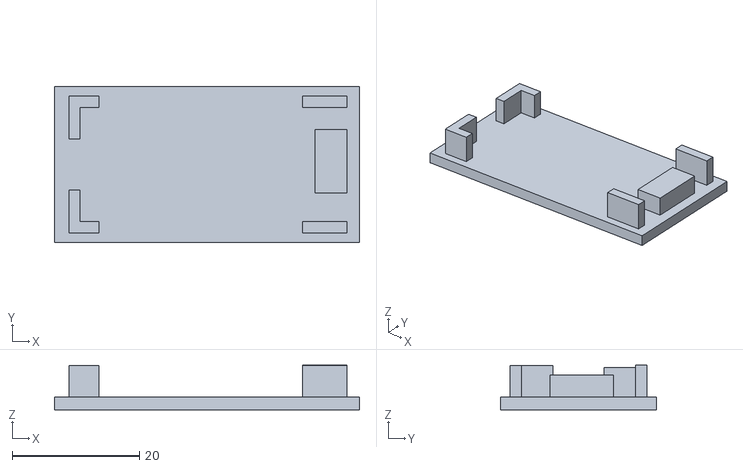
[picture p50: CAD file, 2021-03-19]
STL/TapaArduinoNanoStemfie.stl
48.0 x 24.6 x 7.01

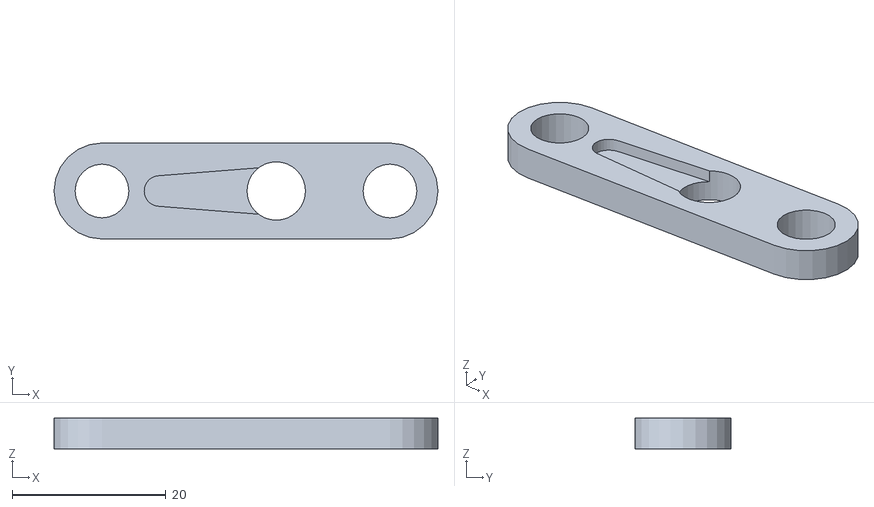
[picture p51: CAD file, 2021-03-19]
STL/Servo9GAdapter_Stemfie.stl
50.0 x 12.5 x 4.00

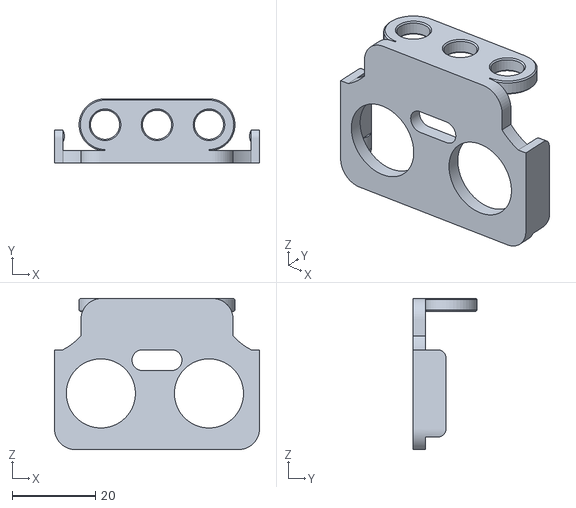
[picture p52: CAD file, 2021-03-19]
STL/SensorAsimetric3H_STEMFIE.stl
49.3 x 15.5 x 36.3

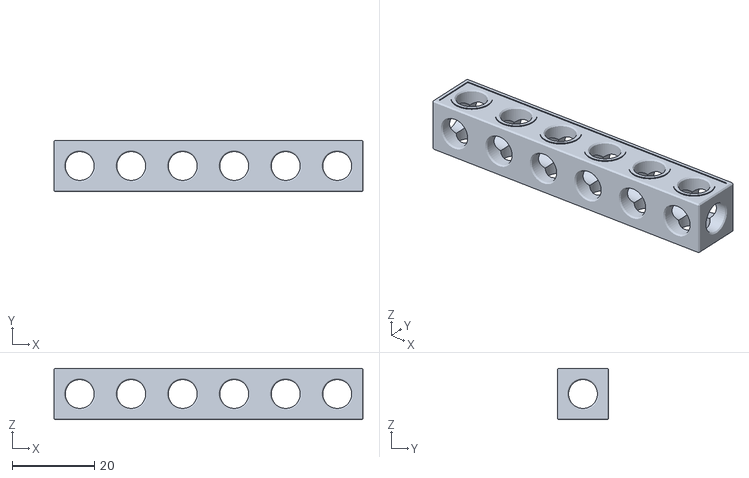
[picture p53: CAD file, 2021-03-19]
STL/beam1x1x6.stl
75.0 x 12.5 x 12.5

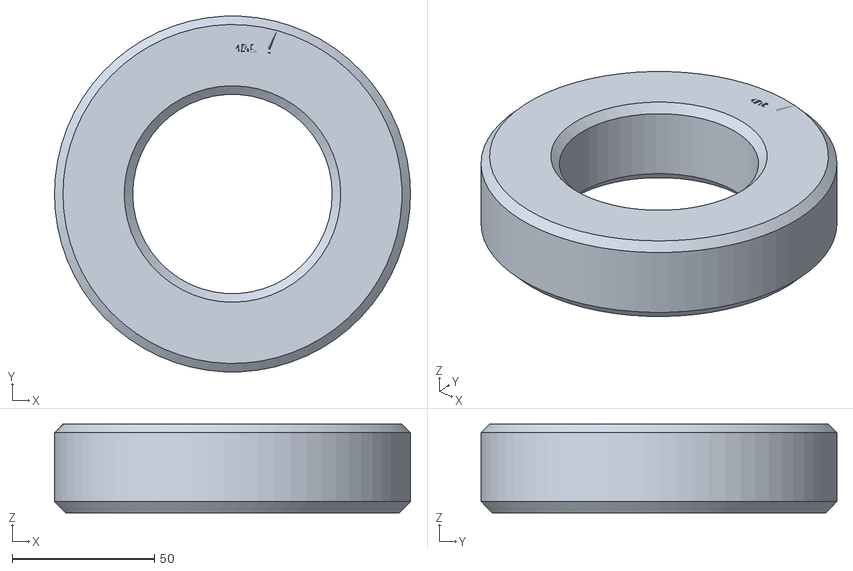
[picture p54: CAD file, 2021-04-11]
STL/Washer.stl
125.0 x 124.8 x 31.2

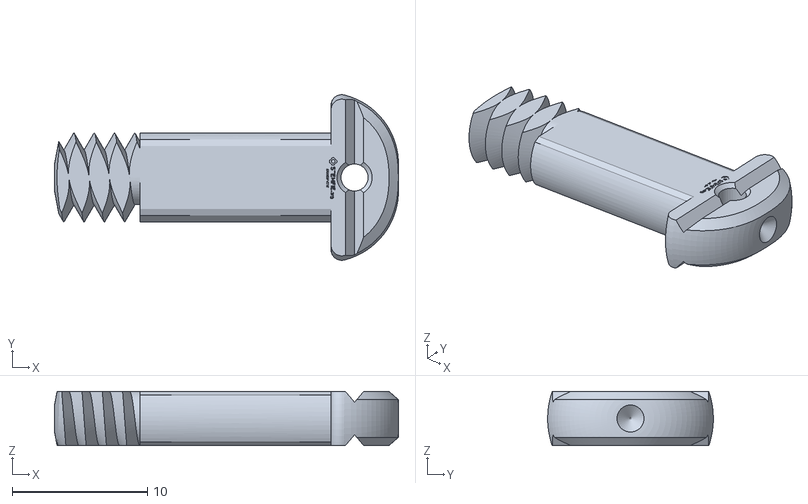
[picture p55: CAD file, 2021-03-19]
STL/ShoulderScrewRHD_RH_BU01.25-SPN-SSC-0045.stl
25.4 x 12.3 x 4.00

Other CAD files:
STL/SensorSimetric3HGuepardBot_STEMFIE2.stl
STL/ShoulderScrewRHD_RH_BU00.75-SPN-SSC-0043.stl
STL/ShoulderScrewRHD_RH_BU00.50-SPN-SSC-0042.stl
STL/ShoulderScrewRHD_RH_BU02.00-SPN-SSC-0048.stl
STL/18650.stl
STL/NutRH_BU01.00x5mm-SPN-NUT-0001.stl
